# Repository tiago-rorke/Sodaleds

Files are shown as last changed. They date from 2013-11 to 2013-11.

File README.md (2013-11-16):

##[Sodaleds](http://www.tiago.co.nz/sodaleds.html)

Modular rectangular LED construction kit. Simple pcb frames allow blocks of 8 leds to be easily powered by a 7.4V source such as a 2-cell Lithium polymer battery.

Contributed to the 2013 Open Mobile project coordinated by [Rita Sá](http://www.rita-sa.com/index.html), with help from [Alt-lab](http://altlab.org/).

All design files licensed under the terms of the [Creative Commons Attribution-NonCommercial-ShareAlike License.](http://creativecommons.org/licenses/by-nc-sa/3.0/legalcode)

###Parts List

Each panel (7 boards) requires 56 LEDs, and 14 resistors.
*	LEDs Rectangular, 5 x 2 x 7mm:
	-	Red - [Digi-Key 754-1201-ND](http://www.digikey.co.uk/product-detail/en/WP113IDT/754-1201-ND/1747600)
	-	Green - [Digi-Key 754-1200-ND](http://www.digikey.com/product-detail/en/WP113GDT/754-1200-ND/1747599)
	-	Yellow - [Digi-Key 754-1203-ND](http://www.digikey.com/product-detail/en/WP113YDT/754-1203-ND/1747602)
*	130Ω 3mm Resistors - [Digi-Key S130QCT-ND](http://www.digikey.com/product-detail/en/CFM14JT130R/S130QCT-ND/2617670)
*	You will need a 7.4V power source, such as a 2-cell lipo battery and a charger.
	-	[HobbyKing Turnigy 500mAh 2S 20C](http://hobbyking.com/hobbyking/store/__9187__Turnigy_500mAh_2S_20C_Lipo_Pack.html)
	-	[HobbyKing B3AC Compact Charger](http://hobbyking.com/hobbyking/store/__22410__HobbyKing_B3AC_Compact_Charger.html)
*	Hook up wire.  A bundle of short, tinned multicore wires would be ideal [such as these](http://www.dhgate.com/product/enameled-wire-23mm-1mm-black-short-wire-welding/143403910.html), but i made my own.  Short jumper wires could work but may be too stiff.
*	For assembling the boards together, wire wrap works well, otherwise small zip ties can work.  String would probably work well.

**Take Note!**
The boards will get a little bit warm when on.  Take this into consideration when arranging the boards so as to avoid putting too much current through a single board.

















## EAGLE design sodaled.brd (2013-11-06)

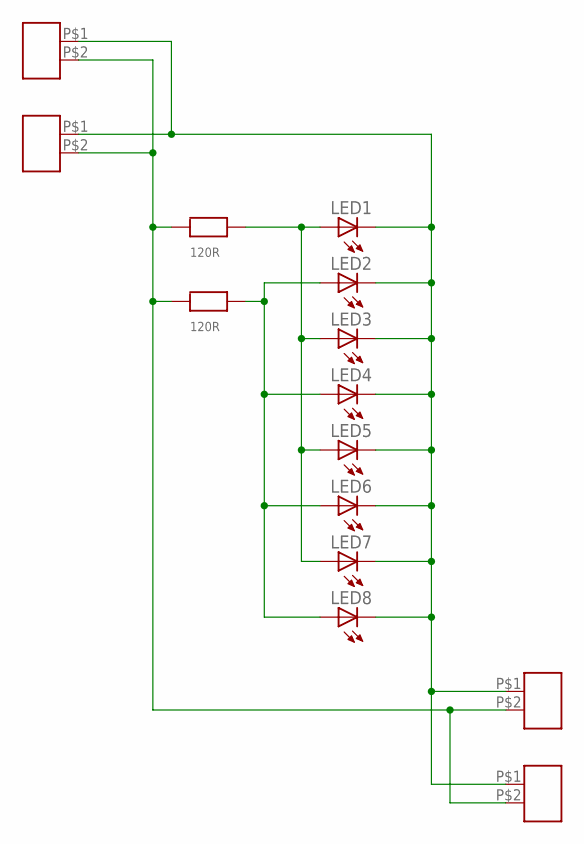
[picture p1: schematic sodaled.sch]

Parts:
LED1, LED2, LED3, LED4, LED5, LED6, LED7, LED8: LEDRECT_SIDE; LED_RECT_SIDEMOUNT
U$1, U$2, U$3, U$4: M02; 1X02
U$7, U$8: 120R; RESISTOR_CFM1

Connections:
7.4V: U$1.P$2, U$2.P$2, U$3.P$2, U$4.P$2, U$7.P$1, U$8.P$1
GND: LED1.C, LED2.C, LED3.C, LED4.C, LED5.C, LED6.C, LED7.C, LED8.C, U$1.P$1, U$2.P$1, U$3.P$1, U$4.P$1
unnamed: LED1.A, LED3.A, LED5.A, LED7.A, U$7.P$2
unnamed: LED2.A, LED4.A, LED6.A, LED8.A, U$8.P$2

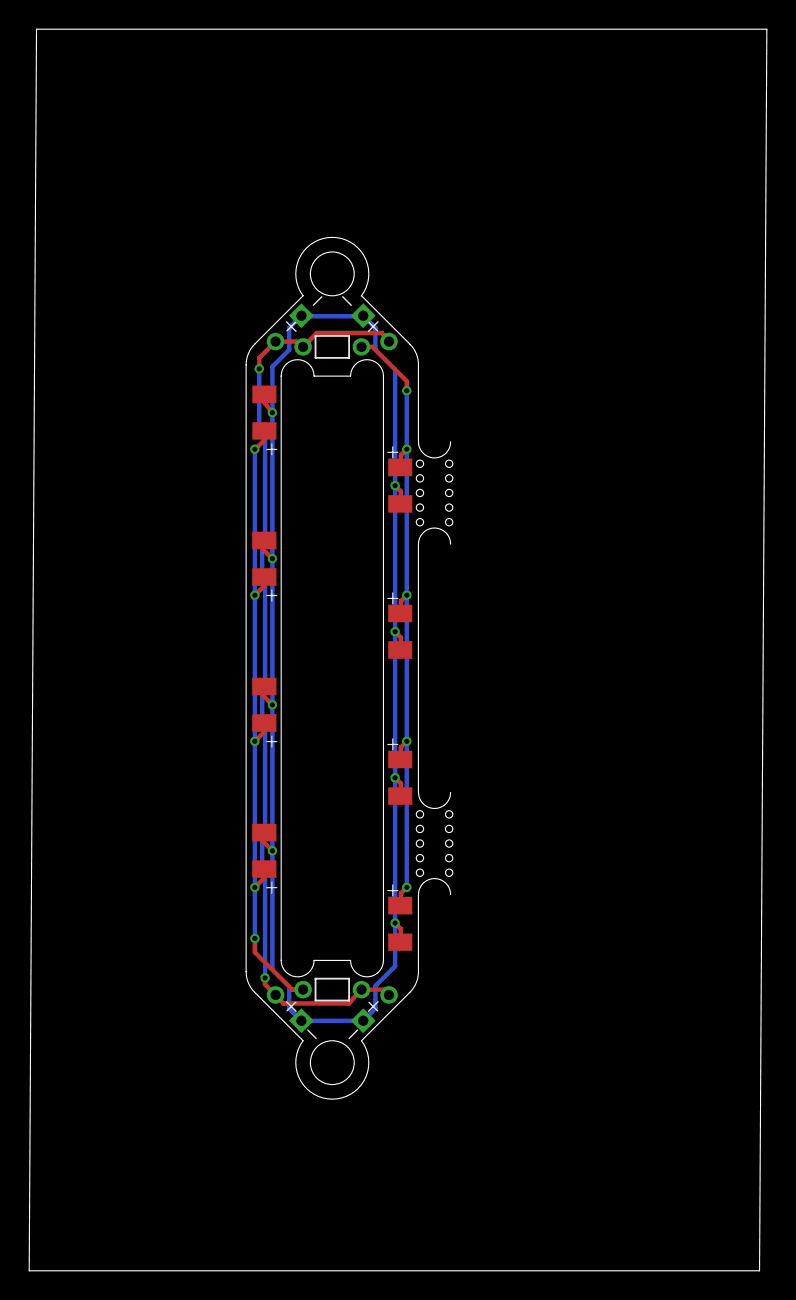
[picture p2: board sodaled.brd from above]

Board: 2 copper layers, 50.5 x 85.0 mm, 14 parts (0 on the bottom side), 4 nets.

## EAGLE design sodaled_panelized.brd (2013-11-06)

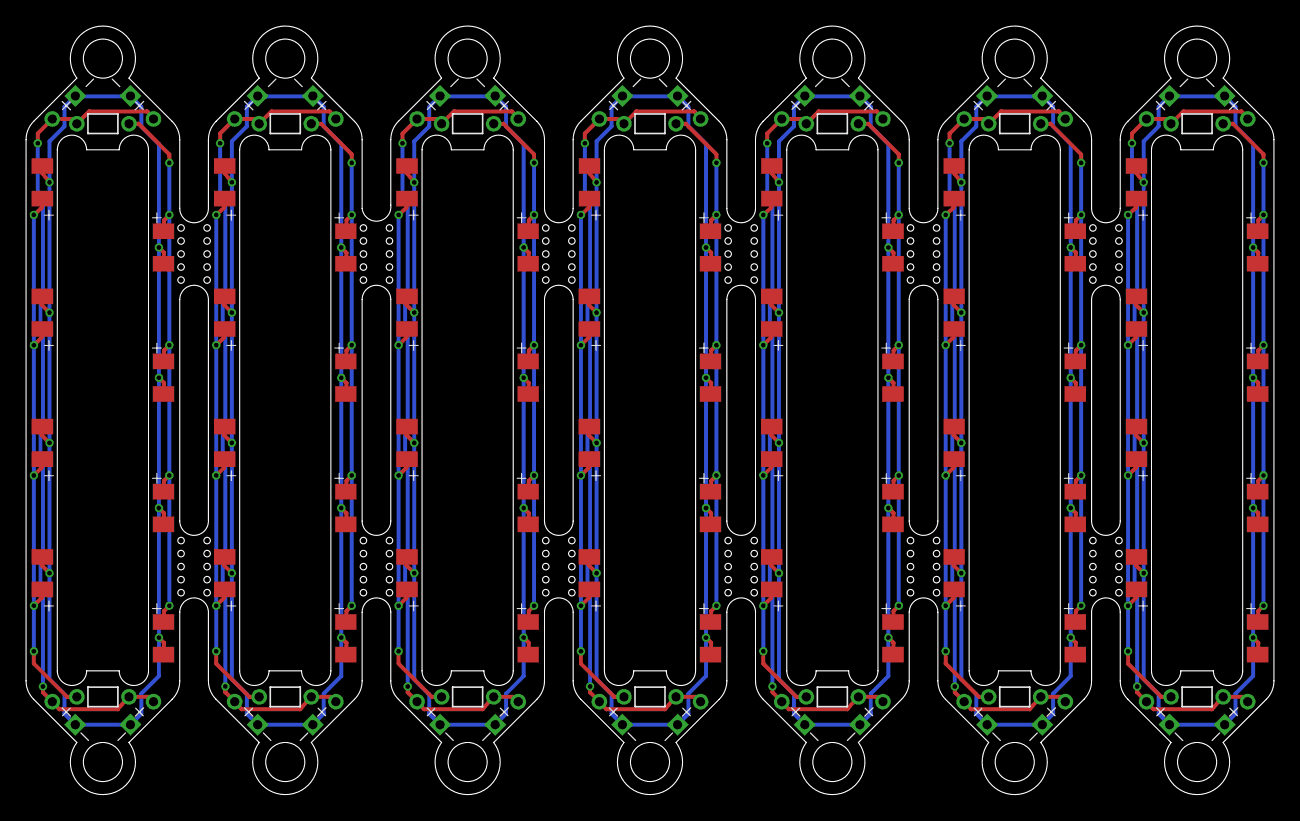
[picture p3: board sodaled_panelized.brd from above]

Board: 2 copper layers, 95.8 x 59.0 mm, 98 parts (0 on the bottom side), 28 nets.

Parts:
LED1, LED2, LED3, LED4, LED5, LED6, LED7, LED8, LED9, LED10, LED11, LED12, LED13, LED14, LED15, LED16, LED17, LED18, LED19, LED20, LED21, LED22, LED23, LED24, LED25, LED26, LED27, LED28, LED29, LED30, LED31, LED32, LED33, LED34, LED35, LED36, LED37, LED38, LED39, LED40, LED41, LED42, LED43, LED44, LED45, LED46, LED47, LED48, LED49, LED50, LED51, LED52, LED53, LED54, LED55, LED56: LED_RECT_SIDEMOUNT
U$1, U$2, U$3, U$4, U$5, U$6, U$9, U$10, U$13, U$14, U$15, U$16, U$19, U$20, U$21, U$22, U$25, U$26, U$27, U$28, U$31, U$32, U$33, U$34, U$37, U$38, U$39, U$40: M02; 1X02
U$7, U$8, U$11, U$12, U$17, U$18, U$23, U$24, U$29, U$30, U$35, U$36, U$41, U$42: 120R; RESISTOR_CFM1

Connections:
7.4V: U$1.P$2, U$2.P$2, U$3.P$2, U$4.P$2, U$7.P$1, U$8.P$1
7.4V1: U$5.P$2, U$6.P$2, U$9.P$2, U$10.P$2, U$11.P$1, U$12.P$1
7.4V2: U$13.P$2, U$14.P$2, U$15.P$2, U$16.P$2, U$17.P$1, U$18.P$1
7.4V3: U$19.P$2, U$20.P$2, U$21.P$2, U$22.P$2, U$23.P$1, U$24.P$1
7.4V4: U$25.P$2, U$26.P$2, U$27.P$2, U$28.P$2, U$29.P$1, U$30.P$1
7.4V5: U$31.P$2, U$32.P$2, U$33.P$2, U$34.P$2, U$35.P$1, U$36.P$1
7.4V6: U$37.P$2, U$38.P$2, U$39.P$2, U$40.P$2, U$41.P$1, U$42.P$1
GND: LED1.C, LED2.C, LED3.C, LED4.C, LED5.C, LED6.C, LED7.C, LED8.C, U$1.P$1, U$2.P$1, U$3.P$1, U$4.P$1
GND1: LED9.C, LED10.C, LED11.C, LED12.C, LED13.C, LED14.C, LED15.C, LED16.C, U$5.P$1, U$6.P$1, U$9.P$1, U$10.P$1
GND2: LED17.C, LED18.C, LED19.C, LED20.C, LED21.C, LED22.C, LED23.C, LED24.C, U$13.P$1, U$14.P$1, U$15.P$1, U$16.P$1
GND3: LED25.C, LED26.C, LED27.C, LED28.C, LED29.C, LED30.C, LED31.C, LED32.C, U$19.P$1, U$20.P$1, U$21.P$1, U$22.P$1
GND4: LED33.C, LED34.C, LED35.C, LED36.C, LED37.C, LED38.C, LED39.C, LED40.C, U$25.P$1, U$26.P$1, U$27.P$1, U$28.P$1
GND5: LED41.C, LED42.C, LED43.C, LED44.C, LED45.C, LED46.C, LED47.C, LED48.C, U$31.P$1, U$32.P$1, U$33.P$1, U$34.P$1
GND6: LED49.C, LED50.C, LED51.C, LED52.C, LED53.C, LED54.C, LED55.C, LED56.C, U$37.P$1, U$38.P$1, U$39.P$1, U$40.P$1
unnamed: LED9.A, LED11.A, LED13.A, LED15.A, U$11.P$2
unnamed: LED1.A, LED3.A, LED5.A, LED7.A, U$7.P$2
unnamed: LED2.A, LED4.A, LED6.A, LED8.A, U$8.P$2
unnamed: LED10.A, LED12.A, LED14.A, LED16.A, U$12.P$2
unnamed: LED17.A, LED19.A, LED21.A, LED23.A, U$17.P$2
unnamed: LED18.A, LED20.A, LED22.A, LED24.A, U$18.P$2
unnamed: LED25.A, LED27.A, LED29.A, LED31.A, U$23.P$2
unnamed: LED26.A, LED28.A, LED30.A, LED32.A, U$24.P$2
unnamed: LED33.A, LED35.A, LED37.A, LED39.A, U$29.P$2
unnamed: LED34.A, LED36.A, LED38.A, LED40.A, U$30.P$2
unnamed: LED41.A, LED43.A, LED45.A, LED47.A, U$35.P$2
unnamed: LED42.A, LED44.A, LED46.A, LED48.A, U$36.P$2
unnamed: LED49.A, LED51.A, LED53.A, LED55.A, U$41.P$2
unnamed: LED50.A, LED52.A, LED54.A, LED56.A, U$42.P$2
